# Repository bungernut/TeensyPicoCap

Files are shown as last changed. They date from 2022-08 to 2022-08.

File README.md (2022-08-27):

# TeensyPicoCap

| LOC | Part | Digikey |
| --- | ---  | --- |
| C2  | 4.7uF | 399-C0805C475K4RAC7210CT-ND |
| C3  | 10uF  | 1276-1764-1-ND |
| C4  | 0.1uF | 399-C320C104K5R5TA7305CT-ND |
| C5  | 10nF C0G | 1292-0805N103J500CT-ND | 
| C6 | 47uF | 1276-3063-1-ND | 
| F1 | 500mA Polyfuse | F2112CT-ND | 
|J1-J3 | 2p Term Block | 2057-EBWA-02-B-ND | 
| J9 | RJ45 | 1278-1052-ND |
| J16 | Barrel Jack | CP-002A-ND | 
| R1 | 1k Ref |  |
| R2 | 1k RTD | 223-1807-ND | 
| U1 | PicoCap04 | Mouser: PCAP04-BQFM-24 |

https://www.digikey.com/short/n2d7w2qm

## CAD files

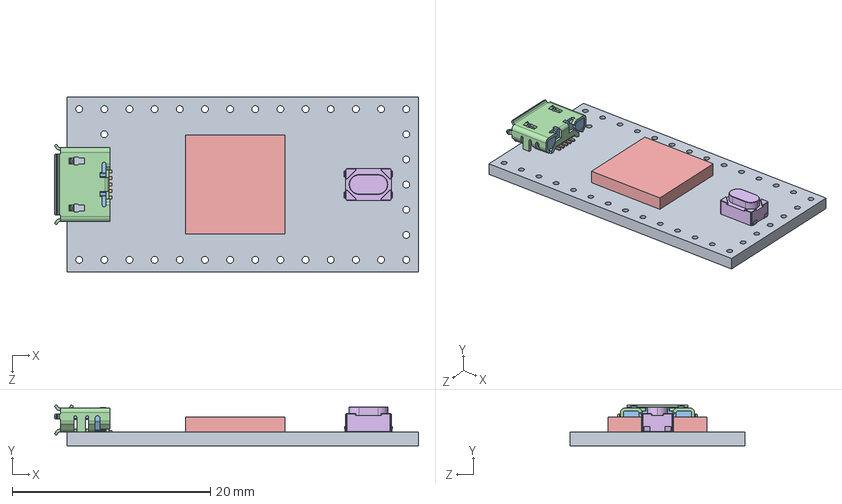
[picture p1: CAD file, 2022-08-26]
PCB/TeensyPicoCap4/teensy.pretty-master/Teensy_4.0_Assembly.STEP
36.8 x 4.12 x 17.7 mm
Teensy_4.0_PCB
Micro USB-B Female 5Pin SMD
NXP iMXRT1062
SKRPACE010 v4

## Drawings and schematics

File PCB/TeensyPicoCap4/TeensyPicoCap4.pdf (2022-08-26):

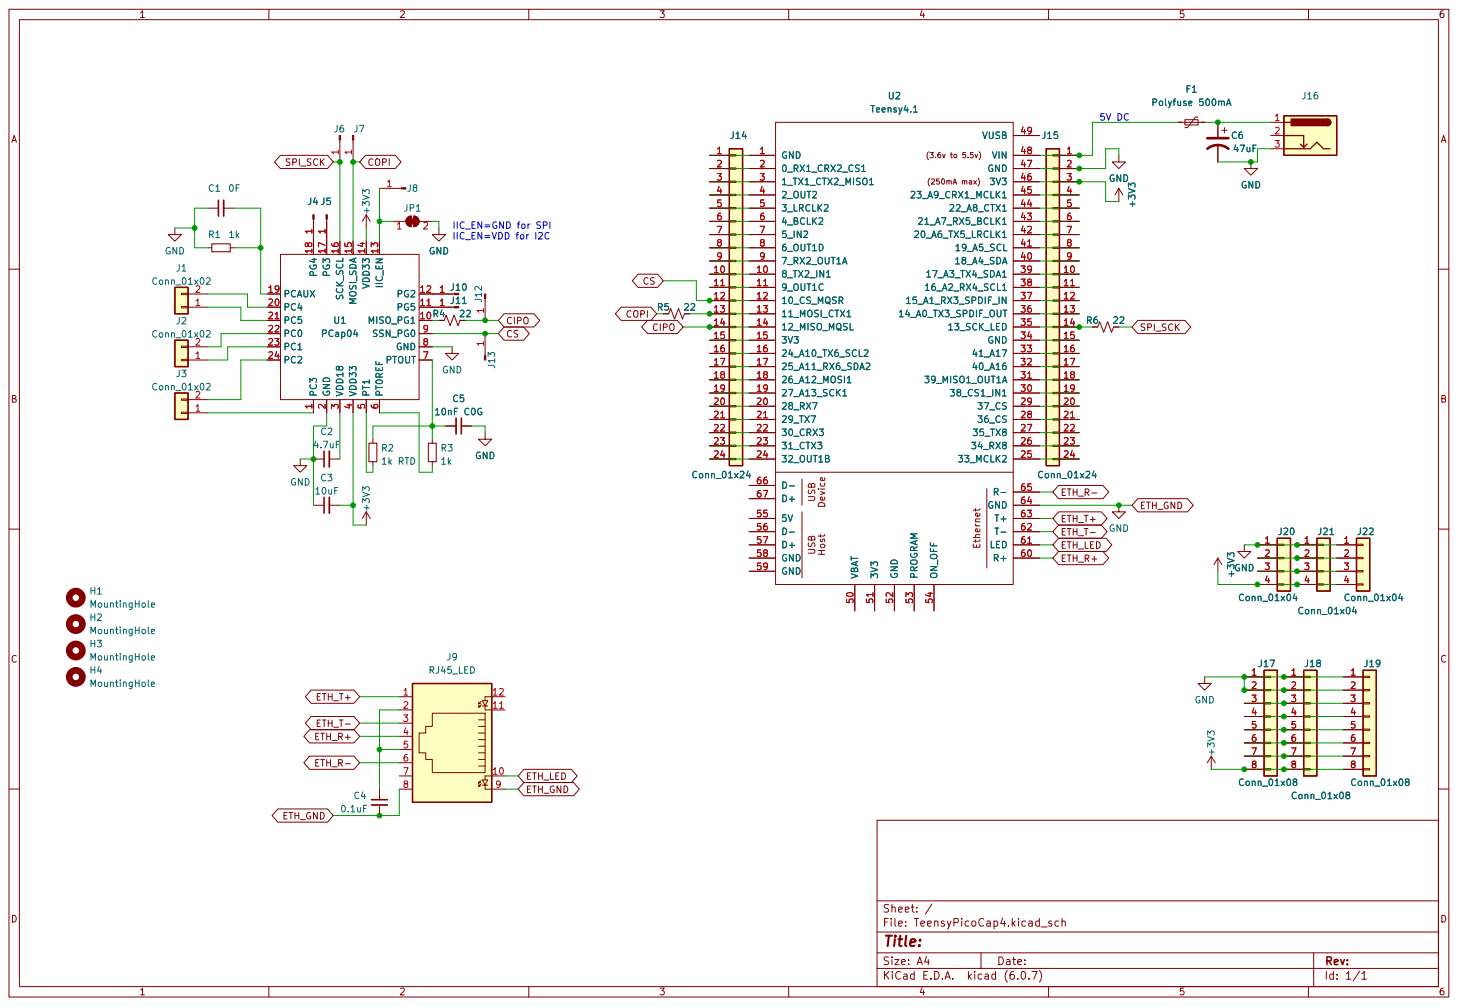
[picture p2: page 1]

11_MOSI_CTX1 13 11_MOSI_CTX1 13 12_MISO_MQSL 14 12_MISO_MQSL 14 3V3 15 3V3 15 24_A10_TX6_SCL2 16 24_A10_TX6_SCL2 16 25_A11_RX6_SDA2 17 25_A11_RX6_SDA2 17 26_A12_MOSI1 18 26_A12_MOSI1 18 27_A13_SCK1 19 27_A13_SCK1 19 28_RX7 20 28_RX7 20 29_TX7 21 29_TX7 21 30_CRX3 22 30_CRX3 22 31_CTX3 23 31_CTX3 23

5V 55 D- 56 D+ 57 GND 58 GND 59

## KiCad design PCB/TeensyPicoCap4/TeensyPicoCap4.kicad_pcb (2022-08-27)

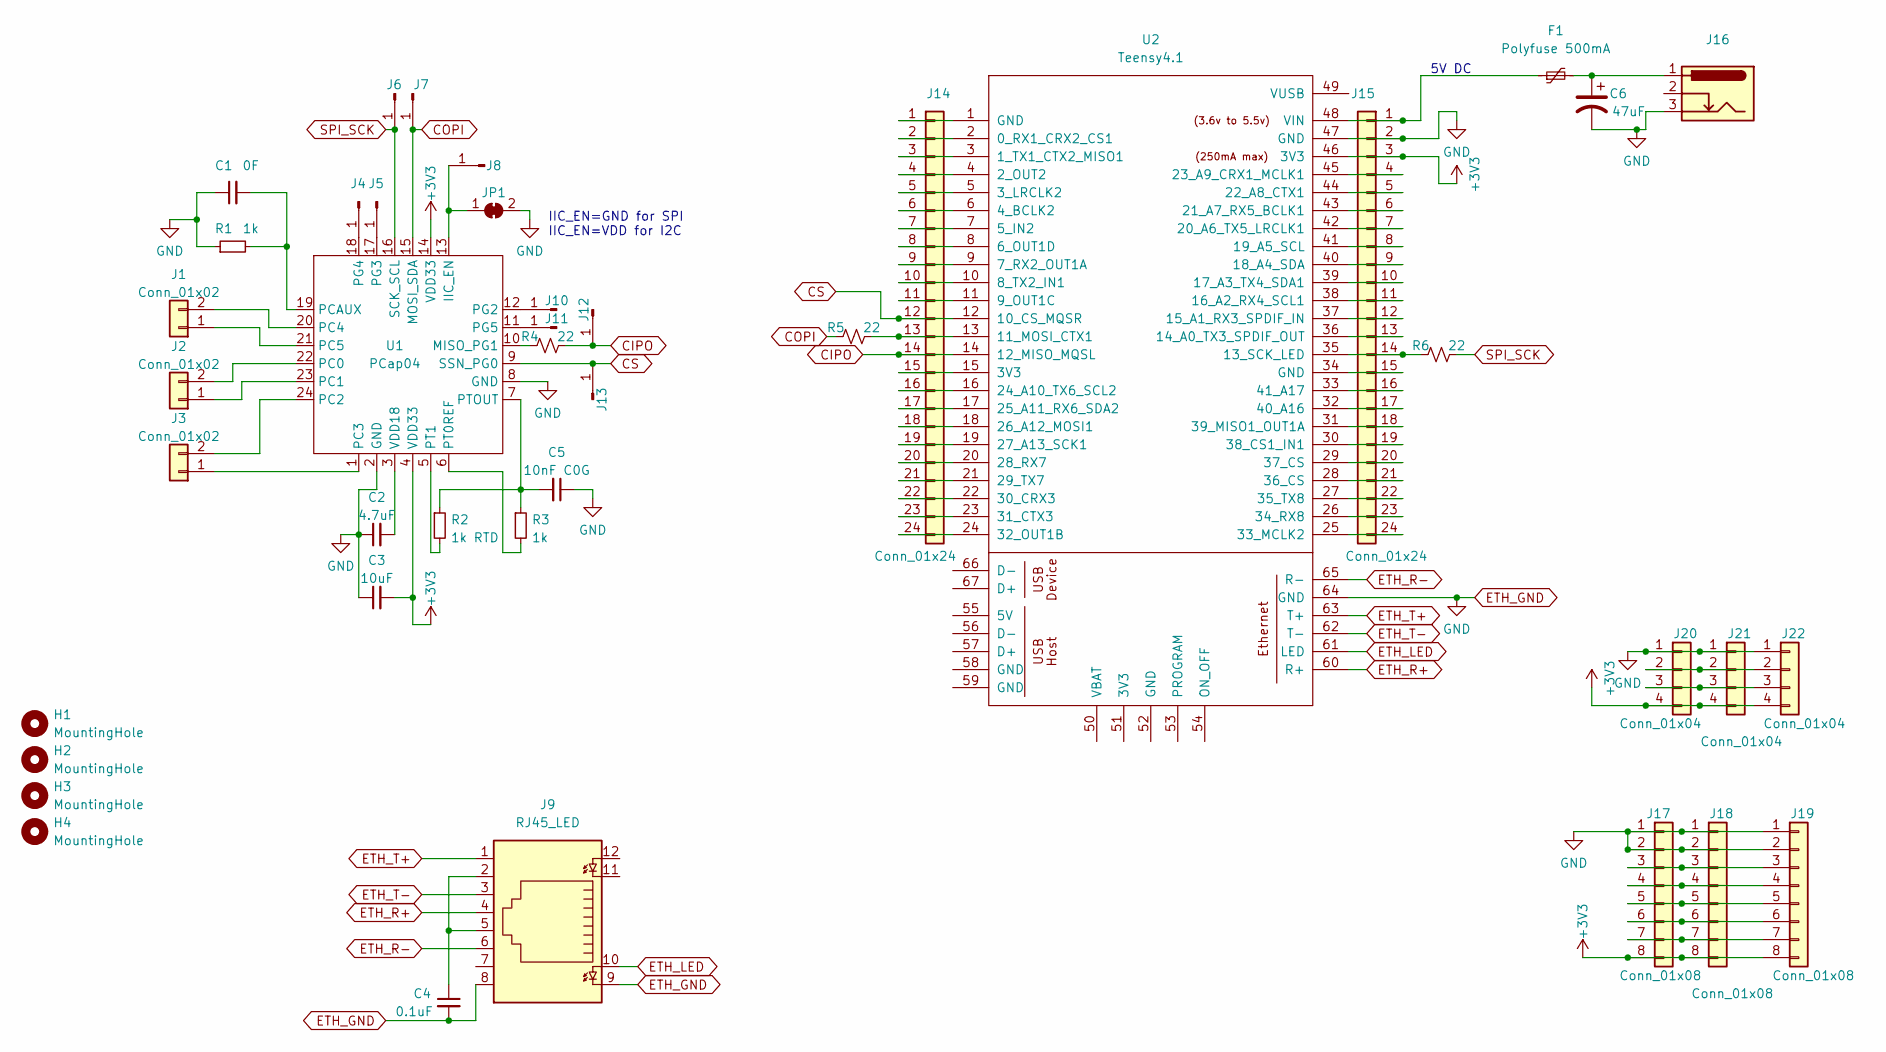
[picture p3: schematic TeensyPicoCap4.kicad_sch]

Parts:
C1: 0F; C_Axial_L5.1mm_D3.1mm_P12.50mm_Horizontal
C2: 4.7uF; C_0805_2012Metric_Pad1.18x1.45mm_HandSolder; Digikey 399-C0805C475K4RAC7210CT-ND
C3: 10uF; C_0805_2012Metric_Pad1.18x1.45mm_HandSolder; Digikey 1276-1764-1-ND
C4: 0.1uF; C_Disc_D3.0mm_W1.6mm_P2.50mm; Digikey 399-C320C104K5R5TA7305CT-ND
C5: 10nF C0G; C_0805_2012Metric_Pad1.18x1.45mm_HandSolder; Digikey 1292-0805N103J500CT-ND
C6: 47uF; C_1206_3216Metric_Pad1.33x1.80mm_HandSolder; Digikey 1276-3063-1-ND
F1: Polyfuse 500mA; Fuse_1206_3216Metric_Pad1.42x1.75mm_HandSolder; Digikey F2112CT-ND
H1, H2, H3, H4: MountingHole; MountingHole_3.2mm_M3
J1, J2, J3: Conn_01x02; PhoenixContact_MCV_1,5_2-G-3.81_1x02_P3.81mm_Vertical; Digikey 2057-EBWA-02-B-ND
J4, J6, J8, J10, J11, J12, J13: Conn_01x01_Male; SolderWire-0.5sqmm_1x01_D0.9mm_OD2.1mm
J5, J7: con; SolderWire-0.5sqmm_1x01_D0.9mm_OD2.1mm
J9: RJ45_LED; RJ45_Cetus_J1B1211CCD_Horizontal; Digikey 1278-1052-ND
J14, J15: Conn_01x24; PinHeader_1x24_P2.54mm_Vertical
J16: Barrel_Jack_Switch_Pin3Ring; BarrelJack_Horizontal; Digikey CP-002A-ND
J17, J18, J19: Conn_01x08; PinHeader_1x08_P2.54mm_Vertical
J20, J21, J22: Conn_01x04; PinHeader_1x04_P2.54mm_Vertical
JP1: SolderJumper_2_Bridged; SolderJumper-2_P1.3mm_Bridged_RoundedPad1.0x1.5mm
R1: 1k; R_Axial_DIN0411_L9.9mm_D3.6mm_P12.70mm_Horizontal
R2: 1k RTD; R_Axial_DIN0204_L3.6mm_D1.6mm_P1.90mm_Vertical; Digikey 223-1807-ND
R3: 1k; R_Axial_DIN0309_L9.0mm_D3.2mm_P12.70mm_Horizontal; Digikey 273-MOX70031001BZE-ND
R4, R5, R6: 22; R_0805_2012Metric_Pad1.20x1.40mm_HandSolder
U1: PCap04; QFN-24-1EP_4x4mm_P0.5mm_EP2.6x2.6mm
U2: Teensy4.1; Teensy41

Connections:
+3V3: C3.2, J15.3, J17.8, J18.8, J19.8, J20.4, J21.4, J22.4, U1.4 (VDD33), U1.14 (VDD33), U2.46 (3V3)
CIPO: J12.1, J14.14, R4.2, U2.14 (12_MISO_MQSL)
COPI: J7.1, R5.1, U1.15 (MOSI_SDA)
CS: J13.1, J14.12, U1.9 (SSN_PG0), U2.12 (10_CS_MQSR)
ETH_GND: C1.1, C2.1, C3.1, C4.2, C5.1, C6.2, J9.8, J9.9, J15.2, J16.3, J17.1, J17.2, J18.1, J18.2, J19.1, J19.2, J20.1, J21.1, J22.1, JP1.2 (B), R1.1, U1.2 (GND), U1.8 (GND), U2.47 (GND), U2.64 (GND)
ETH_LED: J9.10, U2.61 (LED)
ETH_R+: J9.4, U2.60 (R+)
ETH_R-: J9.6, U2.65 (R-)
ETH_T+: J9.1, U2.63 (T+)
ETH_T-: J9.3, U2.62 (T-)
unnamed: C1.2, R1.2, U1.19 (PCAUX)
unnamed: C2.2, U1.3 (VDD18)
unnamed: C4.1, J9.2, J9.5
unnamed: C5.2, R2.1, R3.1, U1.7 (PTOUT)
unnamed: C6.1, F1.2, J16.1
unnamed: F1.1, J15.1, U2.48 (VIN)
unnamed: J1.1, U1.21 (PC5)
unnamed: J1.2, U1.20 (PC4)
unnamed: J2.1, U1.23 (PC1)
unnamed: J2.2, U1.22 (PC0)
unnamed: J3.1, U1.1 (PC3)
unnamed: J3.2, U1.24 (PC2)
unnamed: J4.1, U1.18 (PG4)
unnamed: J5.1, U1.17 (PG3)
unnamed: J8.1, JP1.1 (A), U1.13 (IIC_EN)
unnamed: J10.1, U1.12 (PG2)
unnamed: J11.1, U1.11 (PG5)
unnamed: J14.1, U2.1 (GND)
unnamed: J14.2, U2.2 (0_RX1_CRX2_CS1)
unnamed: J14.3, U2.3 (1_TX1_CTX2_MISO1)
unnamed: J14.4, U2.4 (2_OUT2)
unnamed: J14.5, U2.5 (3_LRCLK2)
unnamed: J14.6, U2.6 (4_BCLK2)
unnamed: J14.7, U2.7 (5_IN2)
unnamed: J14.8, U2.8 (6_OUT1D)
unnamed: J14.9, U2.9 (7_RX2_OUT1A)
unnamed: J14.10, U2.10 (8_TX2_IN1)
unnamed: J14.11, U2.11 (9_OUT1C)
unnamed: J14.13, R5.2, U2.13 (11_MOSI_CTX1)
unnamed: J14.15, U2.15 (3V3)
unnamed: J14.16, U2.16 (24_A10_TX6_SCL2)
unnamed: J14.17, U2.17 (25_A11_RX6_SDA2)
unnamed: J14.18, U2.18 (26_A12_MOSI1)
unnamed: J14.19, U2.19 (27_A13_SCK1)
unnamed: J14.20, U2.20 (28_RX7)
unnamed: J14.21, U2.21 (29_TX7)
unnamed: J14.22, U2.22 (30_CRX3)
unnamed: J14.23, U2.23 (31_CTX3)
unnamed: J14.24, U2.24 (32_OUT1B)
unnamed: J15.4, U2.45 (23_A9_CRX1_MCLK1)
unnamed: J15.5, U2.44 (22_A8_CTX1)
unnamed: J15.6, U2.43 (21_A7_RX5_BCLK1)
unnamed: J15.7, U2.42 (20_A6_TX5_LRCLK1)
unnamed: J15.8, U2.41 (19_A5_SCL)
unnamed: J15.9, U2.40 (18_A4_SDA)
unnamed: J15.10, U2.39 (17_A3_TX4_SDA1)
unnamed: J15.11, U2.38 (16_A2_RX4_SCL1)
unnamed: J15.12, U2.37 (15_A1_RX3_SPDIF_IN)
unnamed: J15.13, U2.36 (14_A0_TX3_SPDIF_OUT)
unnamed: J15.14, R6.1, U2.35 (13_SCK_LED)
unnamed: J15.15, U2.34 (GND)
unnamed: J15.16, U2.33 (41_A17)
unnamed: J15.17, U2.32 (40_A16)
unnamed: J15.18, U2.31 (39_MISO1_OUT1A)
unnamed: J15.19, U2.30 (38_CS1_IN1)
unnamed: J15.20, U2.29 (37_CS)
unnamed: J15.21, U2.28 (36_CS)
unnamed: J15.22, U2.27 (35_TX8)
unnamed: J15.23, U2.26 (34_RX8)
unnamed: J15.24, U2.25 (33_MCLK2)
unnamed: J17.3, J18.3, J19.3
unnamed: J17.4, J18.4, J19.4
unnamed: J17.5, J18.5, J19.5
unnamed: J17.6, J18.6, J19.6
unnamed: J17.7, J18.7, J19.7
unnamed: J20.2, J21.2, J22.2
unnamed: J20.3, J21.3, J22.3
unnamed: R2.2, U1.5 (PT1)
unnamed: R3.2, U1.6 (PT0REF)
unnamed: R4.1, U1.10 (MISO_PG1)
SPI_SCK: J6.1, R6.2, U1.16 (SCK_SCL)

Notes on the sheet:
5V DC
IIC_EN=GND for SPI IIC_EN=VDD for I2C

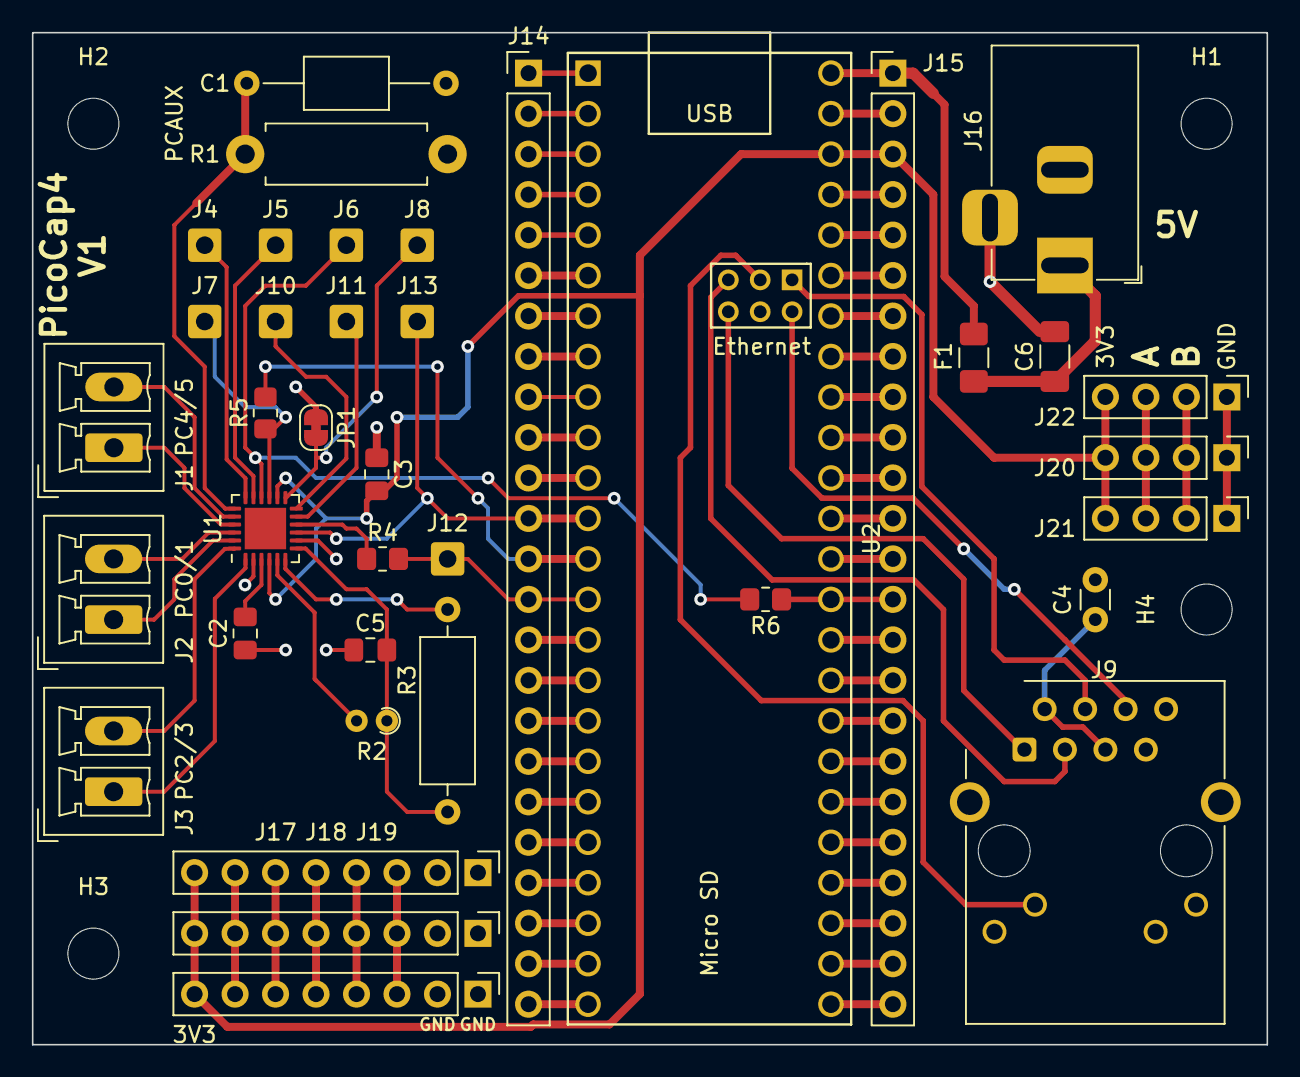
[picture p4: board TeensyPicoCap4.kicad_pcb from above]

Board: 2 copper layers, 77.5 x 63.5 mm, 42 parts (0 on the bottom side), 81 nets.

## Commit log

2022-08-18 initial commit, still working on sch
    [TeensyPicoCap.kicad_pcb, TeensyPicoCap.kicad_sch]
2022-08-26 first design
    [TeensyPicoCap4.kicad_pcb, TeensyPicoCap4.kicad_sch, Teensy_4.0_Assembly.STEP]
2022-08-26 remove temp work
    [TeensyPicoCap.kicad_pcb, TeensyPicoCap.kicad_sch]
2022-08-27 submitted V1 w/ more silk and digikey parts
    [TeensyPicoCap4.kicad_pcb, TeensyPicoCap4.kicad_sch]
